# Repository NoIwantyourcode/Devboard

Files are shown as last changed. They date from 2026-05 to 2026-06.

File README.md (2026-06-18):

# What is this Devboard

This is a custom devboard I have made which uses an RP2040 along with 40 GPIO pins, This also has an inbuild MPU-6500 IMU for all of your tilt and acceleration measuring needs!

# Why I built this

I built this because I was extremely bored on one fine Sunday morning and decided to embark on this project to teach myself about robots and how to design them

# Pictures of the Devboard

  # Schematics - DevBoard
  

  # PCB board - DevBoard
  

  # PCB Board - 3D render
  
  

  # PCB board assembled and working!
  

  # Demo!
  Goto <li>https://youtu.be/vsxfW2zVnzc</li>

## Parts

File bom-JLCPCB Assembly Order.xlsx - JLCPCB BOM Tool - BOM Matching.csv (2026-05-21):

JLCPCB BOM Tool - BOM Matching
BOM name：bom-JLCPCB Assembly Order.xlsx |  |  | Download Time：2026-05-21 21:02:26
PCB Assembled Qty：2 |  |  | Total Price：$69.17 (incl. shipping)
Your BOM |  |  |  |  | Order Information
Top Designator | Bottom Designator | Comment | Footprint | Footprint | JLCPCB Part # | Product link | Lib Type | Qty | Source | Total Price ($)
C1 |  | 1uF | 0402 | 0402 | C52923 | https://jlcpcb.com/partdetail/53938-CL05A105KA5NQNC/C52923 | Basic | 2 | 2 JLCPCB | 0.008
C10,C11,C12,C17,C2,C3,C4,C5,C6,C7,C8,C9 |  | 0.1uF | 0402 | 0402 | C1525 | https://jlcpcb.com/partdetail/1877-CL05B104KO5NNNC/C1525 | Basic | 24 | 24 JLCPCB | 0.036
C13,C14 |  | 10uF | 0603 | 0603 | C19702 | https://jlcpcb.com/partdetail/20411-CL10A106KP8NNNC/C19702 | Basic | 4 | 4 JLCPCB | 0.0408
C15,C16 |  | 15pF | 0402 | 0402 | C1548 | https://jlcpcb.com/partdetail/1900-0402CG150J500NT/C1548 | Basic | 4 | 4 JLCPCB | 0.0048
C18 |  | 47uF | 0603 | 0603 | C140782 | https://jlcpcb.com/partdetail/152108-GRM188R60J476ME15D/C140782 | Extended | 6 | 6 JLCPCB | 0.375
C19 |  | 10nF | 0603 | 0603 | C57112 | https://jlcpcb.com/partdetail/58143-0603B103K500NT/C57112 | Basic | 2 | 2 JLCPCB | 0.0062
C20,C21 |  | 0.1uF | 0603 | 0603 | C14663 | https://jlcpcb.com/partdetail/YAGEO-CC0603KRX7R9BB104/C14663 | Basic | 4 | 4 JLCPCB | 0.012
D1 |  | SS14 | D_SMA | SMA(DO-214AC) | C2480 | https://jlcpcb.com/partdetail/MDD_Microdiode_Semiconductor-SS14/C2480 | Basic | 2 | 2 JLCPCB | 0.0334
IC1 |  | MPU-6500 | QFN40P300X300X95-25N-D | QFN-24-EP(3x3) | C50278 | https://jlcpcb.com/partdetail/TDKInvenSense-MPU6500/C50278 | Extended | 2 | 2 JLCPCB | 12.446
J1 |  | USB_C_Receptacle_USB2.0_14P | USB_C_Receptacle_HRO_TYPE-C-31-M-12 | SMD | C165948 | https://jlcpcb.com/partdetail/Korean_HropartsElec-TYPE_C_31_M12/C165948 | Extended | 2 | 2 JLCPCB | 0.37
R1,R2 |  | 5.1K | 0402 | 0402 | C25905 | https://jlcpcb.com/partdetail/26648-0402WGF5101TCE/C25905 | Basic | 4 | 4 JLCPCB | 0.0036
R3,R4 |  | 27 | 0402 | 0402 | C25100 | https://jlcpcb.com/partdetail/25843-0402WGF270JTCE/C25100 | Extended | 20 | 20 JLCPCB | 0.016
R5,R6 |  | 1K | 0402 | 0402 | C11702 | https://jlcpcb.com/partdetail/12256-0402WGF1001TCE/C11702 | Basic | 4 | 4 JLCPCB | 0.004
R7 |  | 10K | 0402 | 0402 | C25744 | https://jlcpcb.com/partdetail/26487-0402WGF1002TCE/C25744 | Basic | 2 | 2 JLCPCB | 0.0026
R8 |  | 100K | 0603 | 0603 | C25803 | https://jlcpcb.com/partdetail/26546-0603WAF1003T5E/C25803 | Basic | 2 | 2 JLCPCB | 0.0036
SW1 |  | SW_Push | SW_Push_SPST_NO_Alps_SKRK | SMD,3.1x2.5mm | C843684 | https://jlcpcb.com/partdetail/GSwitch-GT_TC032A_H015L1/C843684 | Extended | 5 | 5 JLCPCB | 0.9495
U1 |  | RP2040 | QFN-56-1EP_7x7mm_P0.4mm_EP3.2x3.2mm | LQFN-56(7x7) | C2040 | https://jlcpcb.com/partdetail/RaspberryPi-RP2040/C2040 | Extended | 2 | 2 JLCPCB | 1.9616
U2 |  | NCP1117-3.3_SOT223 | SOT-223-3_TabPin2 | SOT-223 | C26537 | https://jlcpcb.com/partdetail/onsemi-NCP1117ST33T3G/C26537 | Extended | 2 | 2 JLCPCB | 0.4668
U3 |  | W25Q128JVS | SOIC-8_5.3x5.3mm_P1.27mm | SOIC-8-208mil | C97521 | https://jlcpcb.com/partdetail/WinbondElec-W25Q128JVSIQ/C97521 | Basic | 2 | 2 JLCPCB | 4.9598
Y1 |  | 12Mhz | Crystal_SMD_3225-4Pin_3.2x2.5mm | SMD3225-4P | C481407 | https://jlcpcb.com/partdetail/NDK-NX3225GA_12MHZ_STD_CRG2/C481407 | Extended | 5 | 5 JLCPCB | 1.1485
J2 |  | Conn_01x03 | PinHeader_1x03_P2.54mm_Vertical |  |  | https://www.aliexpress.com/item/4001053521664.html?curPageLogUid=cide6r518ULA |  |  |  | -
J3,J4 |  | Conn_01x20 | PinHeader_1x20_P2.54mm_Vertical |  |  | https://www.aliexpress.com/item/4001053521664.html?curPageLogUid=cide6r518ULA |  |  |  | 2.27
J5 |  | JST_2mm_LiPo | JST_XA_S02B-XASK-1N-BN_1x02_P2.50mm_Horizontal |  |  | https://www.aliexpress.com/item/1005009483624961.html?scm_id=1007.40050.354490.0&scm-url=1007.40050.354490.0 |  |  |  | 0.7

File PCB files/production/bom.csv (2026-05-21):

Designator | Footprint | Quantity | Value | LCSC Part #
C1 | 0402 | 1 | 1uF
C10, C11, C12, C17, C2, C3, C4, C5, C6, C7, C8, C9 | 0402 | 12 | 0.1uF
C13, C14 | 0603 | 2 | 10uF
C15, C16 | 0402 | 2 | 15pF
C18 | 0603 | 1 | 47uF
C19 | 0603 | 1 | 10nF
C20, C21 | 0603 | 2 | 0.1uF
D1 | D_SMA | 1 | SS14
IC1 | QFN40P300X300X95-25N-D | 1 | MPU-6500
J1 | USB_C_Receptacle_HRO_TYPE-C-31-M-12 | 1 | USB_C_Receptacle_USB2.0_14P
J2 | PinHeader_1x03_P2.54mm_Vertical | 1 | Conn_01x03
J3, J4 | PinHeader_1x20_P2.54mm_Vertical | 2 | Conn_01x20
J5 | JST_XA_S02B-XASK-1N-BN_1x02_P2.50mm_Horizontal | 1 | JST_2mm_LiPo
R1, R2 | 0402 | 2 | 5.1K
R3, R4 | 0402 | 2 | 27
R5, R6 | 0402 | 2 | 1K
R7 | 0402 | 1 | 10K
R8 | 0603 | 1 | 100K
SW1 | SW_Push_SPST_NO_Alps_SKRK | 1 | SW_Push
U1 | QFN-56-1EP_7x7mm_P0.4mm_EP3.2x3.2mm | 1 | RP2040
U2 | SOT-223-3_TabPin2 | 1 | NCP1117-3.3_SOT223
U3 | SOIC-8_5.3x5.3mm_P1.27mm | 1 | W25Q128JVS
Y1 | Crystal_SMD_3225-4Pin_3.2x2.5mm | 1 | 12Mhz

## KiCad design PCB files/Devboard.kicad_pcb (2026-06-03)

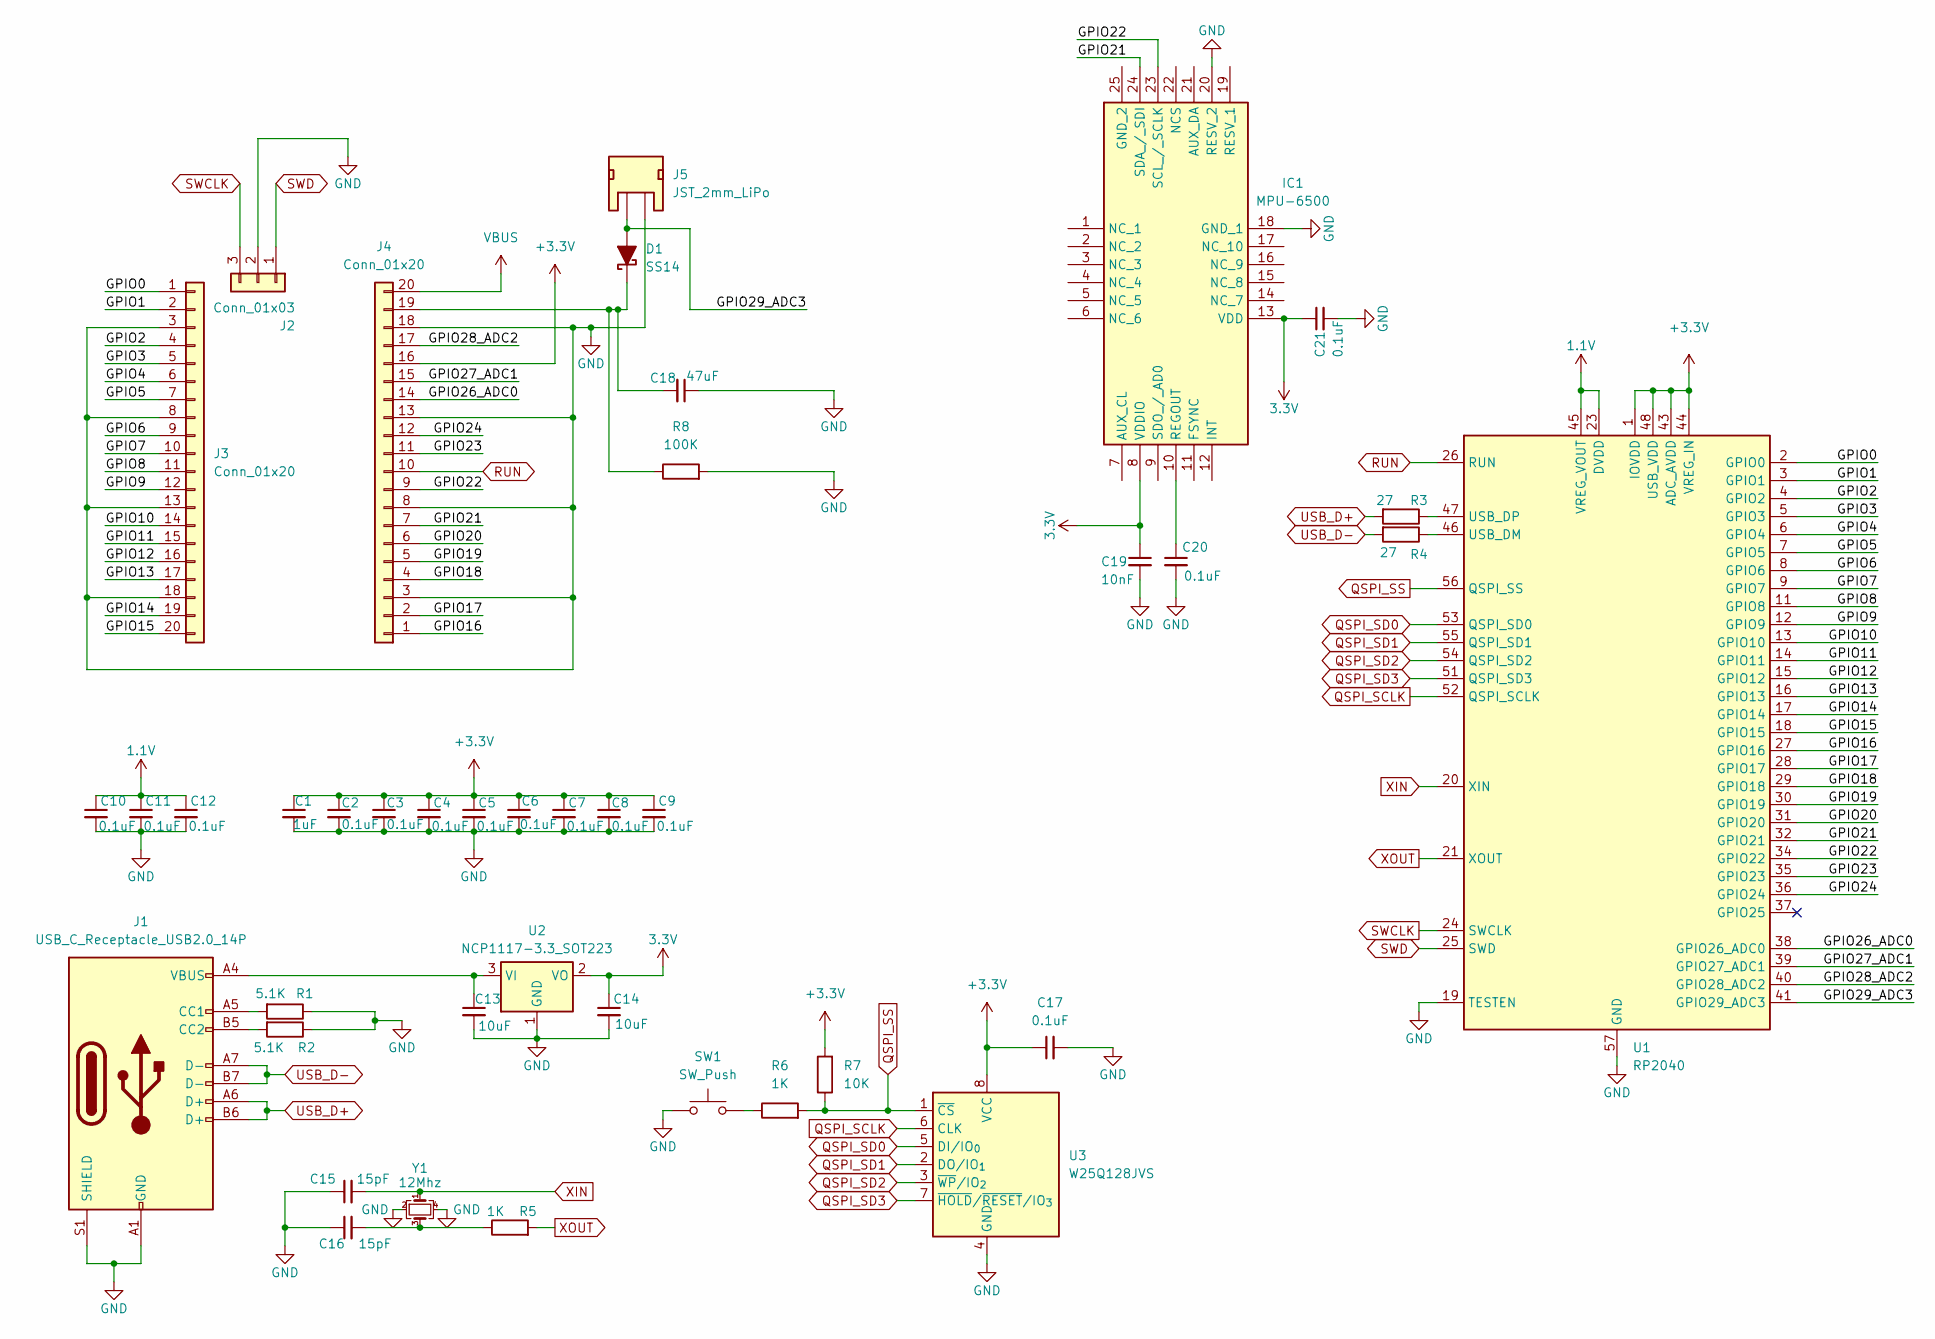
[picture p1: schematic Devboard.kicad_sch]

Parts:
C1: 1uF; C_0402_1005Metric_Pad0.74x0.62mm_HandSolder; Voltage 1kV; Tolerance 100%
C2, C3, C4, C5, C6, C7, C8, C9, C10, C11, C12: 0.1uF; C_0402_1005Metric_Pad0.74x0.62mm_HandSolder; Voltage 1kV; Tolerance 100%
C13, C14: 10uF; C_0603_1608Metric_Pad1.08x0.95mm_HandSolder; Voltage 1kV; Tolerance 100%
C15, C16: 15pF; C_0402_1005Metric; Voltage 50V; Tolerance 5%
C17: 0.1uF; C_0402_1005Metric; Voltage 16V; Tolerance 10%
C18: 47uF; C_0603_1608Metric; Voltage 1kV; Tolerance 100%
C19: 10nF; C_0603_1608Metric; Voltage 1kV; Tolerance 100%
C20, C21: 0.1uF; C_0603_1608Metric; Voltage 1kV; Tolerance 100%
D1: SS14; D_SMA
IC1: MPU-6500; QFN40P300X300X95-25N-D; Manufacturer_Part_Number MPU-6500; Mouser Part Number 410-MPU-6500
J1: USB_C_Receptacle_USB2.0_14P; USB_C_Receptacle_HRO_TYPE-C-31-M-12
J2: Conn_01x03; PinHeader_1x03_P2.54mm_Vertical
J3, J4: Conn_01x20; PinHeader_1x20_P2.54mm_Vertical
J5: JST_2mm_LiPo; JST_XA_S02B-XASK-1N-BN_1x02_P2.50mm_Horizontal
R1, R2: 5.1K; R_0402_1005Metric_Pad0.72x0.64mm_HandSolder
R3, R4: 27; R_0402_1005Metric_Pad0.72x0.64mm_HandSolder
R5, R6: 1K; R_0402_1005Metric_Pad0.72x0.64mm_HandSolder
R7: 10K; R_0402_1005Metric_Pad0.72x0.64mm_HandSolder
R8: 100K; C_0603_1608Metric_Pad1.08x0.95mm_HandSolder
SW1: SW_Push; SW_Push_SPST_NO_Alps_SKRK
U1: RP2040; QFN-56-1EP_7x7mm_P0.4mm_EP3.2x3.2mm
U2: NCP1117-3.3_SOT223; SOT-223-3_TabPin2
U3: W25Q128JVS; SOIC-8_5.3x5.3mm_P1.27mm
Y1: 12Mhz; Crystal_SMD_3225-4Pin_3.2x2.5mm

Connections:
1.1V: C10.1, C11.1, C12.1, U1.23 (DVDD), U1.45 (VREG_VOUT), U1.50 (DVDD)
3.3V: C14.1, C19.1, C21.1, IC1.8 (VDDIO), IC1.13 (VDD), U2.2 (VO)
+3.3V: C1.1, C2.1, C3.1, C4.1, C5.1, C6.1, C7.1, C8.1, C9.1, C17.1, J4.16, R7.2, U1.1 (IOVDD), U1.10 (IOVDD), U1.22 (IOVDD), U1.33 (IOVDD), U1.42 (IOVDD), U1.43 (ADC_AVDD), U1.44 (VREG_IN), U1.48 (USB_VDD), U1.49 (IOVDD), U3.8 (VCC)
/GPIO0: J3.1, U1.2 (GPIO0)
/GPIO1: J3.2, U1.3 (GPIO1)
/GPIO2: J3.4, U1.4 (GPIO2)
/GPIO3: J3.5, U1.5 (GPIO3)
/GPIO4: J3.6, U1.6 (GPIO4)
/GPIO5: J3.7, U1.7 (GPIO5)
/GPIO6: J3.9, U1.8 (GPIO6)
/GPIO7: J3.10, U1.9 (GPIO7)
/GPIO8: J3.11, U1.11 (GPIO8)
/GPIO9: J3.12, U1.12 (GPIO9)
/GPIO10: J3.14, U1.13 (GPIO10)
/GPIO11: J3.15, U1.14 (GPIO11)
/GPIO12: J3.16, U1.15 (GPIO12)
/GPIO13: J3.17, U1.16 (GPIO13)
/GPIO14: J3.19, U1.17 (GPIO14)
/GPIO15: J3.20, U1.18 (GPIO15)
/GPIO16: J4.1, U1.27 (GPIO16)
/GPIO17: J4.2, U1.28 (GPIO17)
/GPIO18: J4.4, U1.29 (GPIO18)
/GPIO19: J4.5, U1.30 (GPIO19)
/GPIO20: J4.6, U1.31 (GPIO20)
/GPIO21: IC1.24 (SDA_/_SDI), J4.7, U1.32 (GPIO21)
/GPIO22: IC1.23 (SCL_/_SCLK), J4.9, U1.34 (GPIO22)
/GPIO23: J4.11, U1.35 (GPIO23)
/GPIO24: J4.12, U1.36 (GPIO24)
/GPIO26_ADC0: J4.14, U1.38 (GPIO26_ADC0)
/GPIO27_ADC1: J4.15, U1.39 (GPIO27_ADC1)
/GPIO28_ADC2: J4.17, U1.40 (GPIO28_ADC2)
/GPIO29_ADC3: D1.2 (A), J5.2 (+), U1.41 (GPIO29_ADC3)
GND: C1.2, C2.2, C3.2, C4.2, C5.2, C6.2, C7.2, C8.2, C9.2, C10.2, C11.2, C12.2, C13.2, C14.2, C15.1, C16.1, C17.2, C18.1, C19.2, C20.2, C21.2, IC1.18 (GND_1), IC1.20 (RESV_2), J1.A1 (GND), J1.A12 (GND), J1.B1 (GND), J1.B12 (GND), J1.S1 (SHIELD), J2.2, J3.3, J3.8, J3.13, J3.18, J4.3, J4.8, J4.13, J4.18, J5.1 (-), R1.1, R2.1, R8.2, SW1.1, U1.19 (TESTEN), U1.57 (GND), U2.1 (GND), U3.4 (GND), Y1.2, Y1.4
unnamed: C16.2, R5.1, Y1.3
unnamed: C18.2, D1.1 (K), J4.19, R8.1
unnamed: C20.1, IC1.10 (REGOUT)
unnamed: J1.A5 (CC1), R1.2
unnamed: J1.B5 (CC2), R2.2
unnamed: R6.1, SW1.2
unnamed: R4.1, U1.46 (USB_DM)
unnamed: R3.1, U1.47 (USB_DP)
unnamed: C13.1, J1.A4 (VBUS), J1.A9 (VBUS), J1.B4 (VBUS), J1.B9 (VBUS), U2.3 (VI)
QSPI_SCLK: U1.52 (QSPI_SCLK), U3.6 (CLK)
QSPI_SD0: U1.53 (QSPI_SD0), U3.5 (DI/IO_{0})
QSPI_SD1: U1.55 (QSPI_SD1), U3.2 (DO/IO_{1})
QSPI_SD2: U1.54 (QSPI_SD2), U3.3 (~WP/IO_{2})
QSPI_SD3: U1.51 (QSPI_SD3), U3.7 (~HOLD/~RESET/IO_{3})
QSPI_SS: R6.2, R7.1, U1.56 (QSPI_SS), U3.1 (~CS)
RUN: J4.10, U1.26 (RUN)
SWCLK: J2.3, U1.24 (SWCLK)
SWD: J2.1, U1.25 (SWD)
USB_D+: J1.A6 (D+), J1.B6 (D+), R3.2
USB_D-: J1.A7 (D-), J1.B7 (D-), R4.2
VBUS: J4.20
XIN: C15.2, U1.20 (XIN), Y1.1
XOUT: R5.2, U1.21 (XOUT)

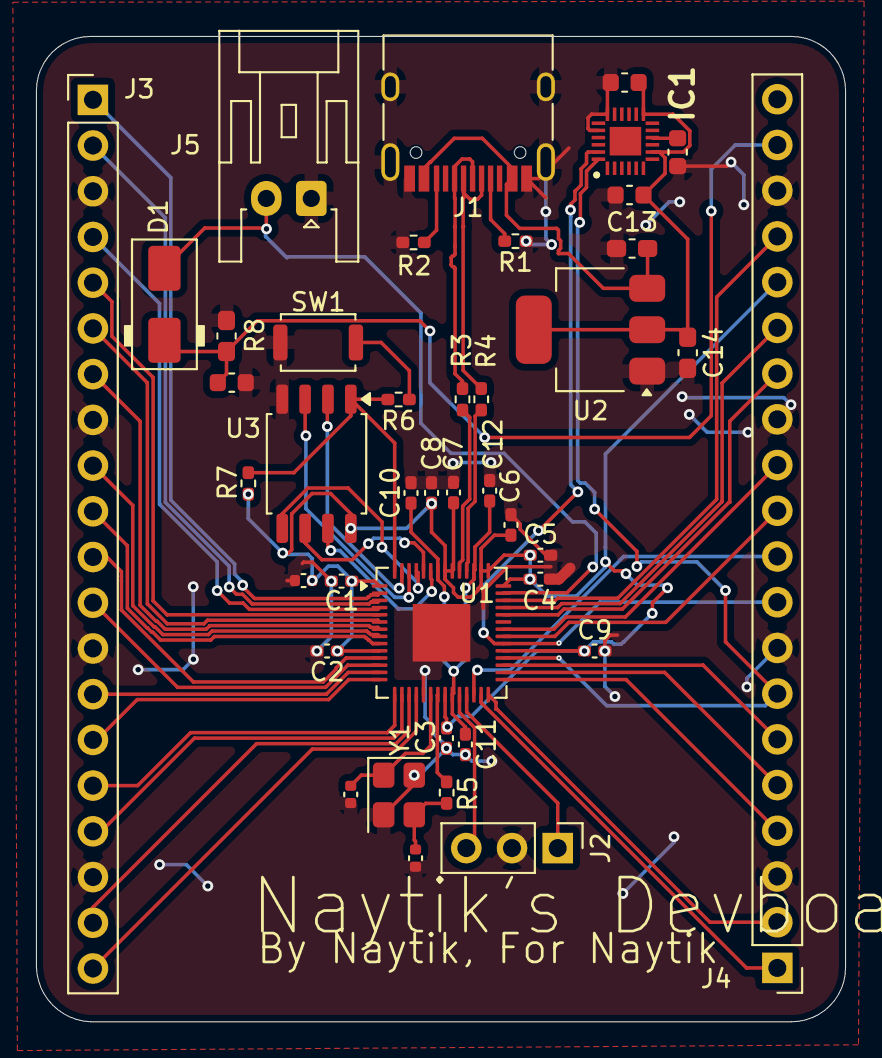
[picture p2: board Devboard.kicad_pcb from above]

Board: 2 copper layers, 44.9 x 54.7 mm, 41 parts (0 on the bottom side), 55 nets.

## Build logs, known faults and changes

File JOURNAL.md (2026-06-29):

**Total Time: 12 hours**

# May 19th: Completed Schematics - 3 hours
I completed the schematics for the devboard, This is very simple devboard however I do plan to add a bunch of features later on such as an IMU (most likely the MPU-6500) and an Magnetometer as well, I may also try to the robot shoot nerf darts out of its back later on so that will be something I might have to add additional hardware for

Heres a picture of the devboard schematic:


# May 20th: Completed routing - 2 hours
I completed the routing, What I ended up with is a 4 layer board with components on both sides, The reason for having components on both sides is space, by optimizing the space I can reduce the power draw of the robot and speed up reaction time of the devboard, even if it maybe marginal! 
This is why it took 5 hours as I had to do multiple iterations with each iteration getting smaller

heres a picture of the 1st V 2nd iteration:




# May 20th: Updated Schematics and PCB - 2 hours
I updated the schematics to include an IMU which will be used to help balance the robot on the 2 wheels it works by!
I also updated the PCB to be routed with the new IMU and made it so that it now has a silkscreen!

heres a picture of the new board

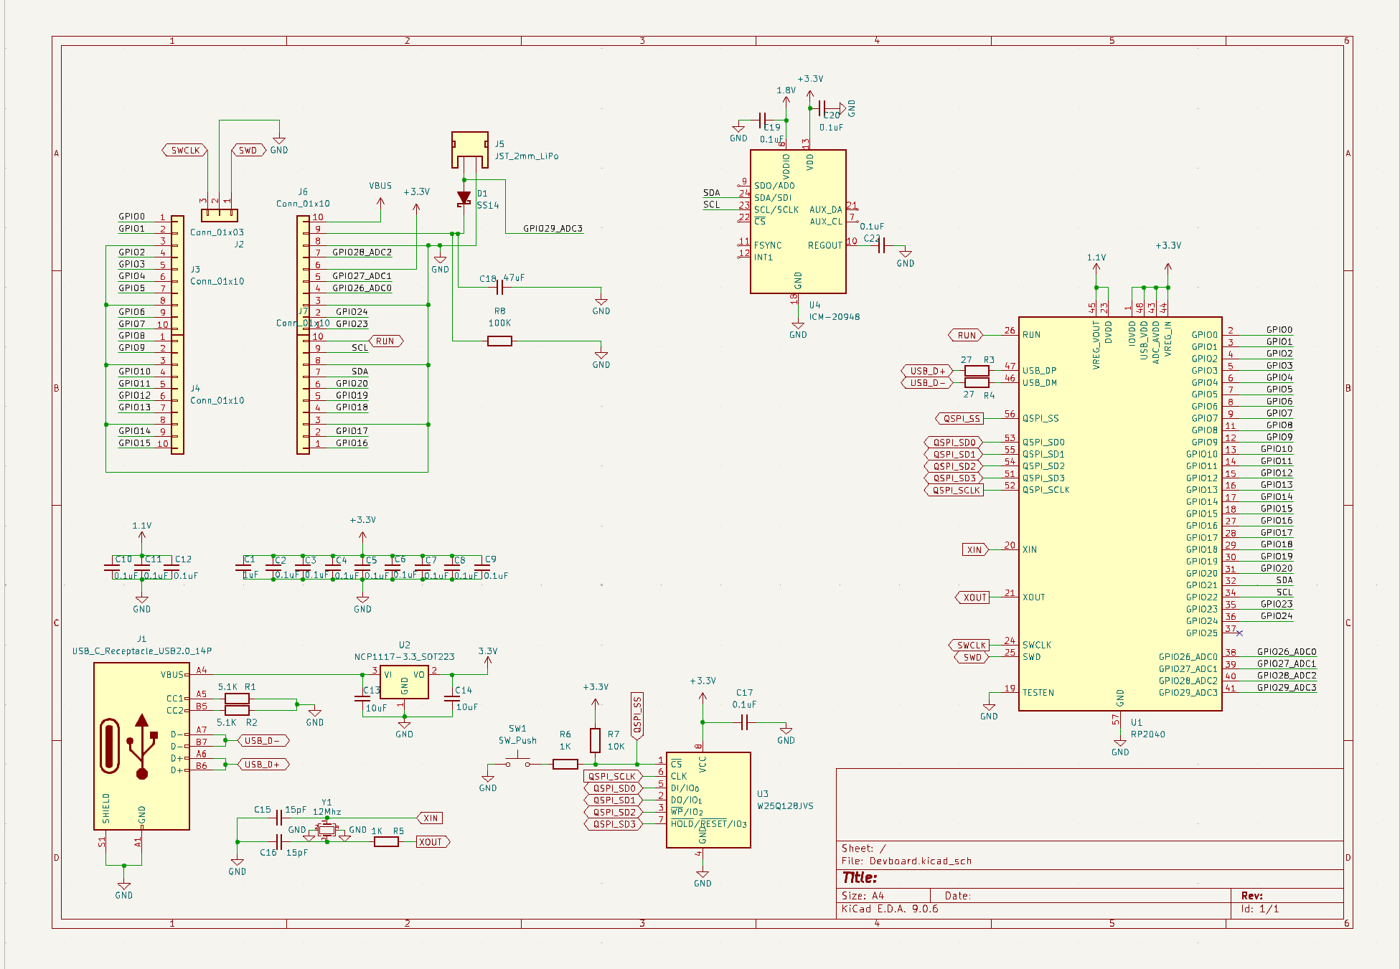
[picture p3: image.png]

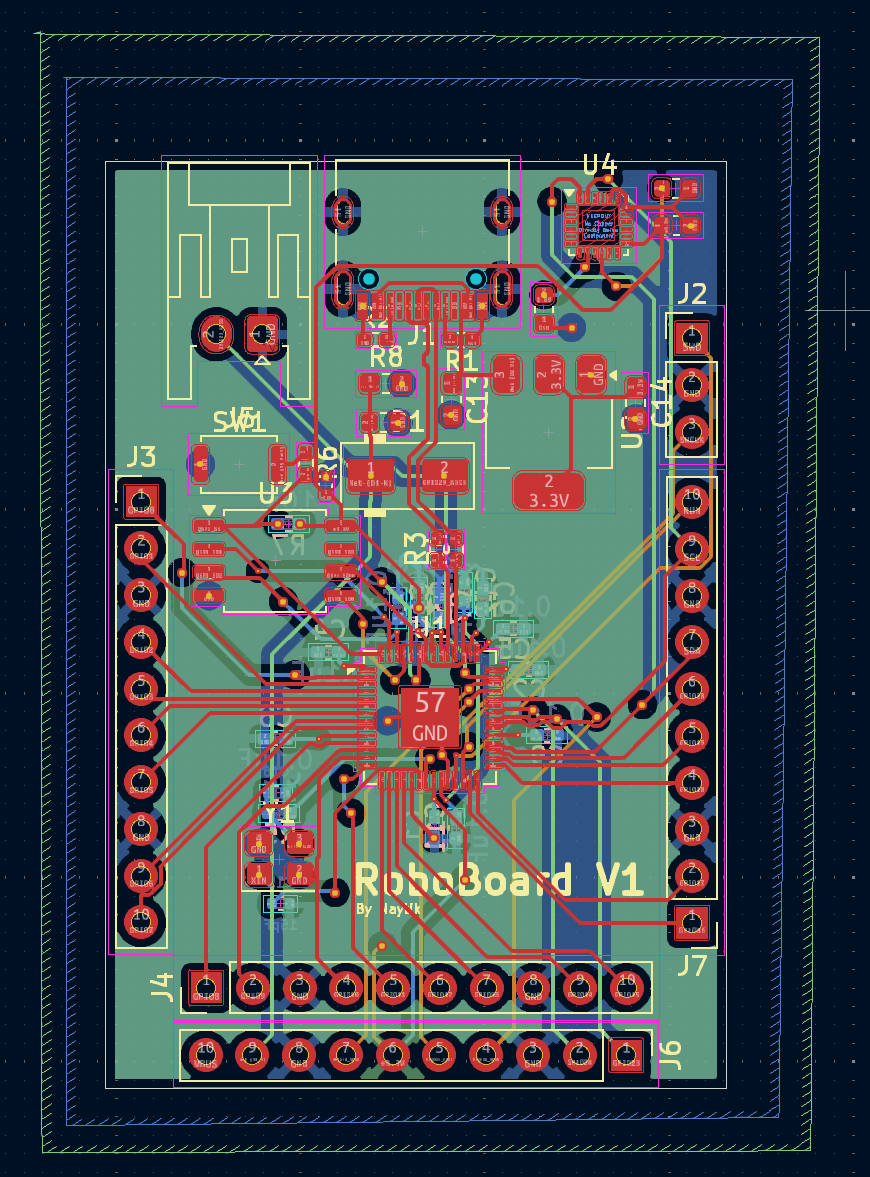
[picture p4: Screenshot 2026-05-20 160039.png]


# May 20th: I rerouted the PCB and removed the IMU - 1.5 hours
I removed the IMU as I couldn't figure out how to power it, I also realised that having 4 10-pin headers to make 40 pins would be inefficient and instead decided to use 2 20-pin headers to make it easier to route and work on later, I also simplified the board to go from a 4-layer PCB to 2-layer PCB

here is a picture of the board now:



# May 21st: Added IMU to the devboard - 0.5 hours
After much research and deliberation, I added an MPU-6500 accelerometer + gyroscope chip, This is what the schematic now looks like



# June 2nd: Added silkscreen art - 0.5 hours
I added some silkscreen art to spice up the devboard, I changed the font on which my name is written and I also added a Tic Tac Toe board to the back so I can play on it





# June 18th: Recived, Assembled and made the devboard and made it work - 2.5 hours
I troubleshooted, assembled and tested the devboard.

When I got my devboard, I realised that it didn’t work because there were 2 3.3v nets and they were not being connected, after linking the 2 3.3v nets together using a bodge wire I realised that the devboard still wasn’t getting enough power as the 3.3v voltage regulator was only outputting 1.3v, I ended up using an Arduno Uno’s 3.3v pins + some jumper cables to provide power to the board.

In the end I was able to make the board work just fine without too many problems!!

here is a picture of the board in the end



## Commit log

2026-05-19 Added an IMU, Solved all DRC thermal relief errors + routed IMU
    [Devboard.kicad_pcb, Devboard.kicad_sch, bom.csv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]
2026-05-19 Changed IMU from MPU-6500 to ICM-20948
    [Devboard.kicad_pcb, Devboard.kicad_sch, bom.csv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]
2026-05-20 Updated Devboard
    [Devboard.kicad_pcb, Devboard.kicad_sch]
2026-05-20 Re-routed the board to a 2-layer PCB and removed IMU unit
    [Devboard.kicad_pcb, Devboard.kicad_sch, bom.csv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]
2026-05-20 Add schematics and PCB board images to README
2026-05-21 added MPU-6500 IMU
    [Devboard.kicad_pcb, Devboard.kicad_sch, bom.csv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]
2026-05-21 removed old production file, new one is in the PCB files folder
    [bom.csv, designators.csv, positions.csv]
2026-05-21 Added extra dimensions
    [Devboard.kicad_pcb]
2026-05-21 added bom
    [bom-JLCPCB Assembly Order.xlsx - JLCPCB BOM Tool - BOM Matching.csv]
2026-05-22 added rounded corners and also added silkscreen text
    [Devboard.kicad_pcb]
2026-05-23 changes for rounded corners!
    [Devboard.kicad_pcb]
2026-05-23 updated for rounded corners
    [Devboard.kicad_pcb, positions.csv]
2026-06-02 I added a tic tac toe board to the back
    [Devboard.kicad_pcb]
2026-06-02 added better art
    [Devboard.kicad_pcb]
2026-06-02 Update PCB images in README.md
2026-06-03 added better silkscreen art
    [Devboard.kicad_pcb]
2026-06-29 Update JOURNAL.md with new entry and total time
    Updated total time and added entry for June 18th detailing assembly and troubleshooting of the devboard.
